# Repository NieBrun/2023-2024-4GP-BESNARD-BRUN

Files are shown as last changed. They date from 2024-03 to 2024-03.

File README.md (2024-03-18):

# 2023-2024 : Capteur low-tech Graphite (Niels Brun &amp; Paul Besnard)

## SOMMAIRE
*** 
  - [Contexte](#contexte)
  - [Livrables](#livrables)
  - [Matériel nécessaire](#matériel-nécessaire)
  - [1. Simulation électronique du capteur sous LTSpice](#simulation-électronique-du-capteur-sous-ltspice)
  - [2. Design du PCB sous KiCad](#design-du-pcb-sous-kicad)
  - [3. Code arduino](#code-arduino)
  - [4. Application android APK sous MIT App Inventor](#application-android-apk-sous-mit-app-inventor)
  - [5. Réalisation du shield](#réalisation-du-shield)
  - [6. Banc de test](#banc-de-test)
  - [7. Datasheet](#datasheet)
  - [Contact](#contact) 

*** 

## Contexte
&nbsp;&nbsp;&nbsp;&nbsp;&nbsp;&nbsp;Dans le cadre de l'UF "Du capteur au banc de test" se déroulant en 4ème année de Génie Physique de l’INSA Toulouse, nous avons développé un dispositif permettant de mesurer la contrainte. Le capteur du dispositif est basé sur l'article "Pencil Drawn Strain Gauges and Chemiresistors on Paper" (Cheng-Wei Lin*, Zhibo Zhao*, Jaemyung Kim & Jiaxing Huang). Il est simplement composé d'un bout de papier avec du crayon à papier. En déformant le papier, le nombre de particules de graphite composant le crayon à papier déposé sur le papier, reliées varie en fonction du type de déformation. Ce système granulaire subit une modification de résistance et de conductance. Grâce à cela, on  pourra remonter à la déformation tel une jauge de contrainte traditionnel. \
&nbsp;&nbsp;&nbsp;&nbsp;&nbsp;&nbsp;L'objectif est donc de pouvoir réaliser un dispositif permettant la mesure de déformation à partir d'un capteur low-tech. En passant par différentes étapes : simulations électroniques, design du PCB, code arduino et réalisation de datasheet.

## Livrables
- Un Shield PCB relié à une carte arduino UNO avec différents composants : un capteur graphite, un amplificateur transimpédance et un module bluetooth. Il peut également avoir un écran OLED, un flex sensor commercial, un potentiomètre digital, encodeur rotatoire ou des boutons.
- Un code arduino qui gère les différents composants cités précédemments (mesures de contraintes, échanges bluetooth et OLED, potentiomètre digital et boutons)
- Une application Android (sous MIT App Inventor) interfaçant le PCB et le code arduino.
- Un code arduino réalisant les essais de banc de test sur les mesures de contraintes.
- Une datasheet sur le capteur de contrainte.

Nous avons opté pour l'ajout d'un écran OLED, du flex sensor commercial, du potentiomètre digital. Egalement, nous avons choisi l'implémentation de 3 boutons plutôt que de l'encodeur rotatoire.

## Matériel nécessaire
Pour réaliser notre dispositif électronique, voici la liste des composants nécessaires :

- Résistances : 2 de 1 kOhms, 5 de 10 kOhms, 2 de 100 kOhms
- Capacités : 2 de 100 nF, 1 de 1 uF
- Arduino Uno
- Amplificateur opérationnel LTC1050
- Potentiomètre digital MCP41500
- Module Bluetooth HC05
- Ecran OLED 128x64
- Flex Sensor
- 3 boutons

## Simulation électronique du capteur sous LTSpice

## Design du PCB sous KiCad

## Code arduino

## Application android APK sous MIT App Inventor

## Réalisation du shield

## Banc de test

## Datasheet

## Contact

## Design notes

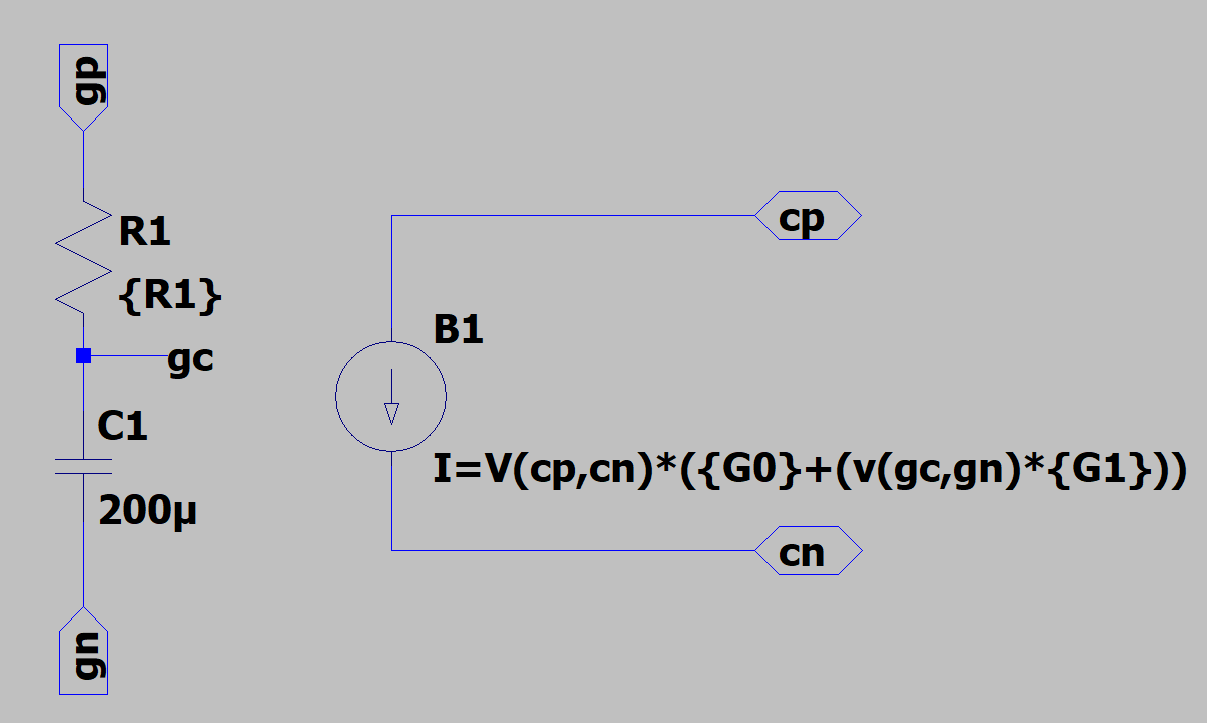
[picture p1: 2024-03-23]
Images/LTspice/capteur.png

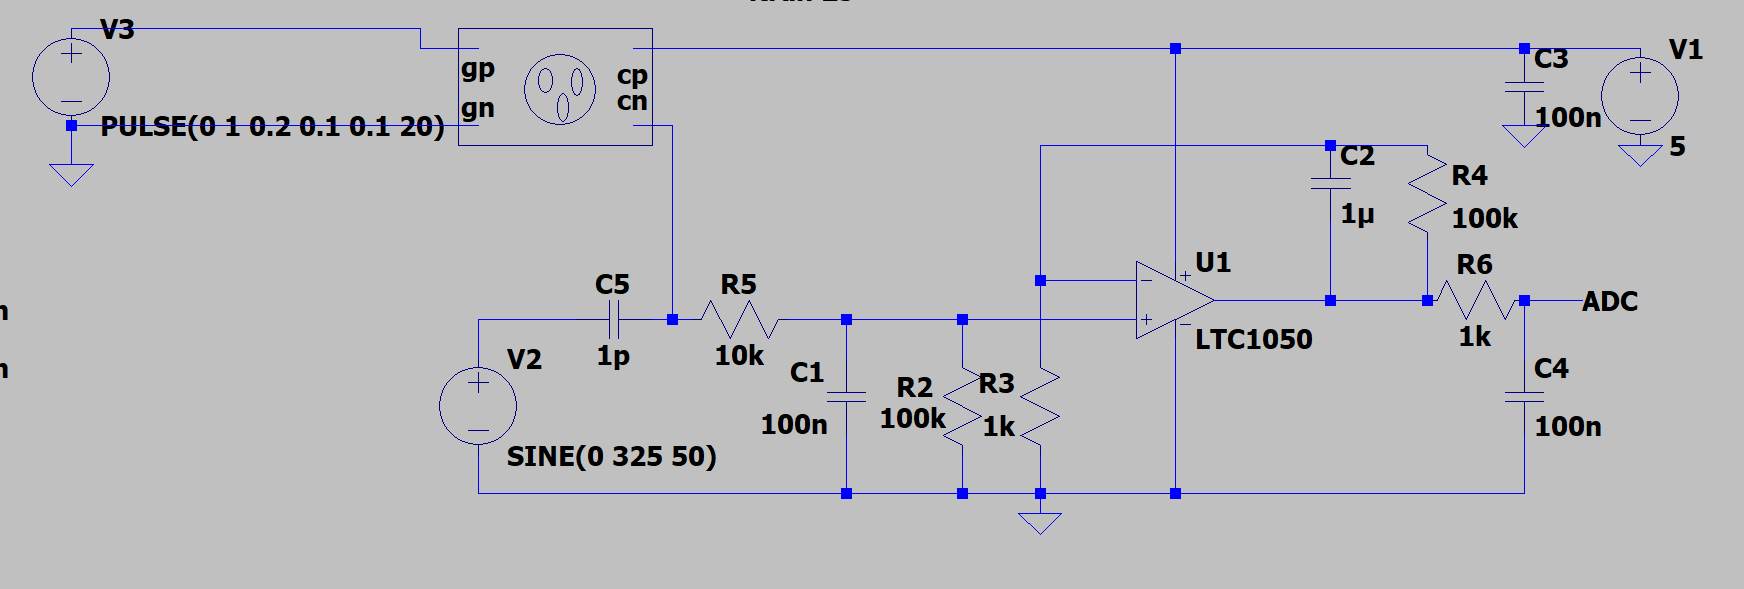
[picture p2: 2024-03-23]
Images/LTspice/schéma_global_ampli.png

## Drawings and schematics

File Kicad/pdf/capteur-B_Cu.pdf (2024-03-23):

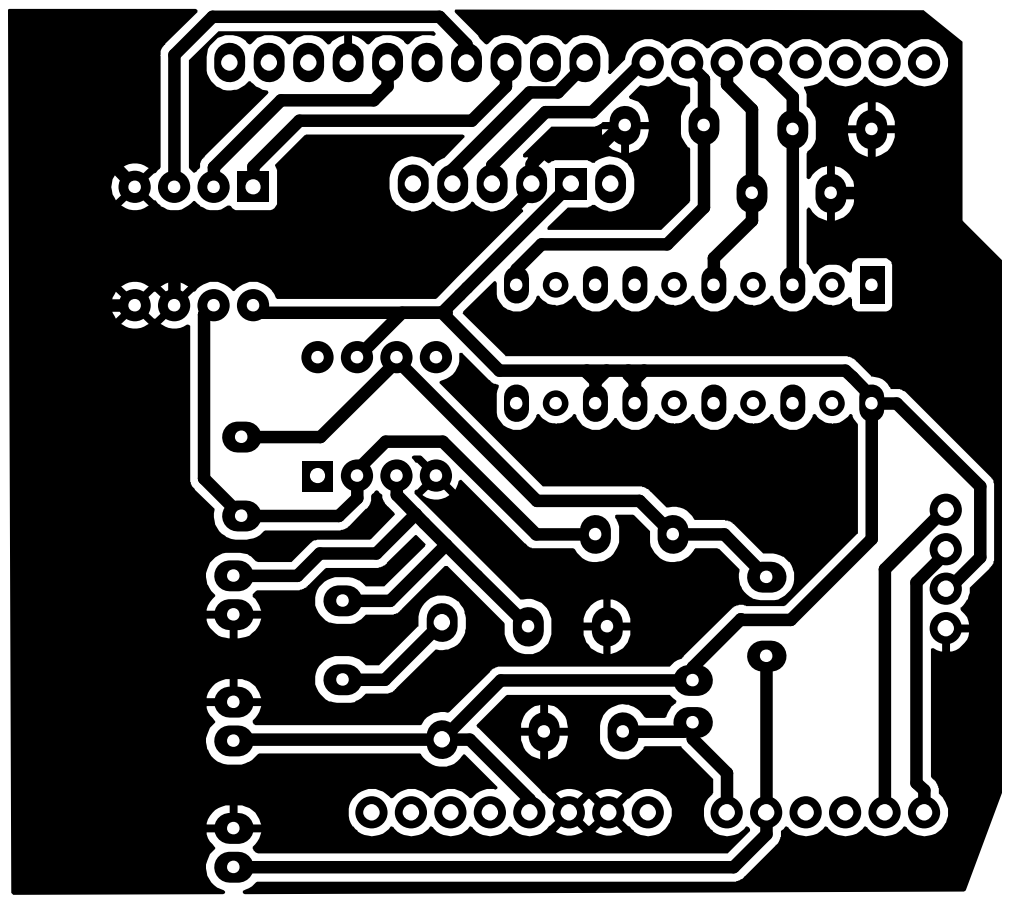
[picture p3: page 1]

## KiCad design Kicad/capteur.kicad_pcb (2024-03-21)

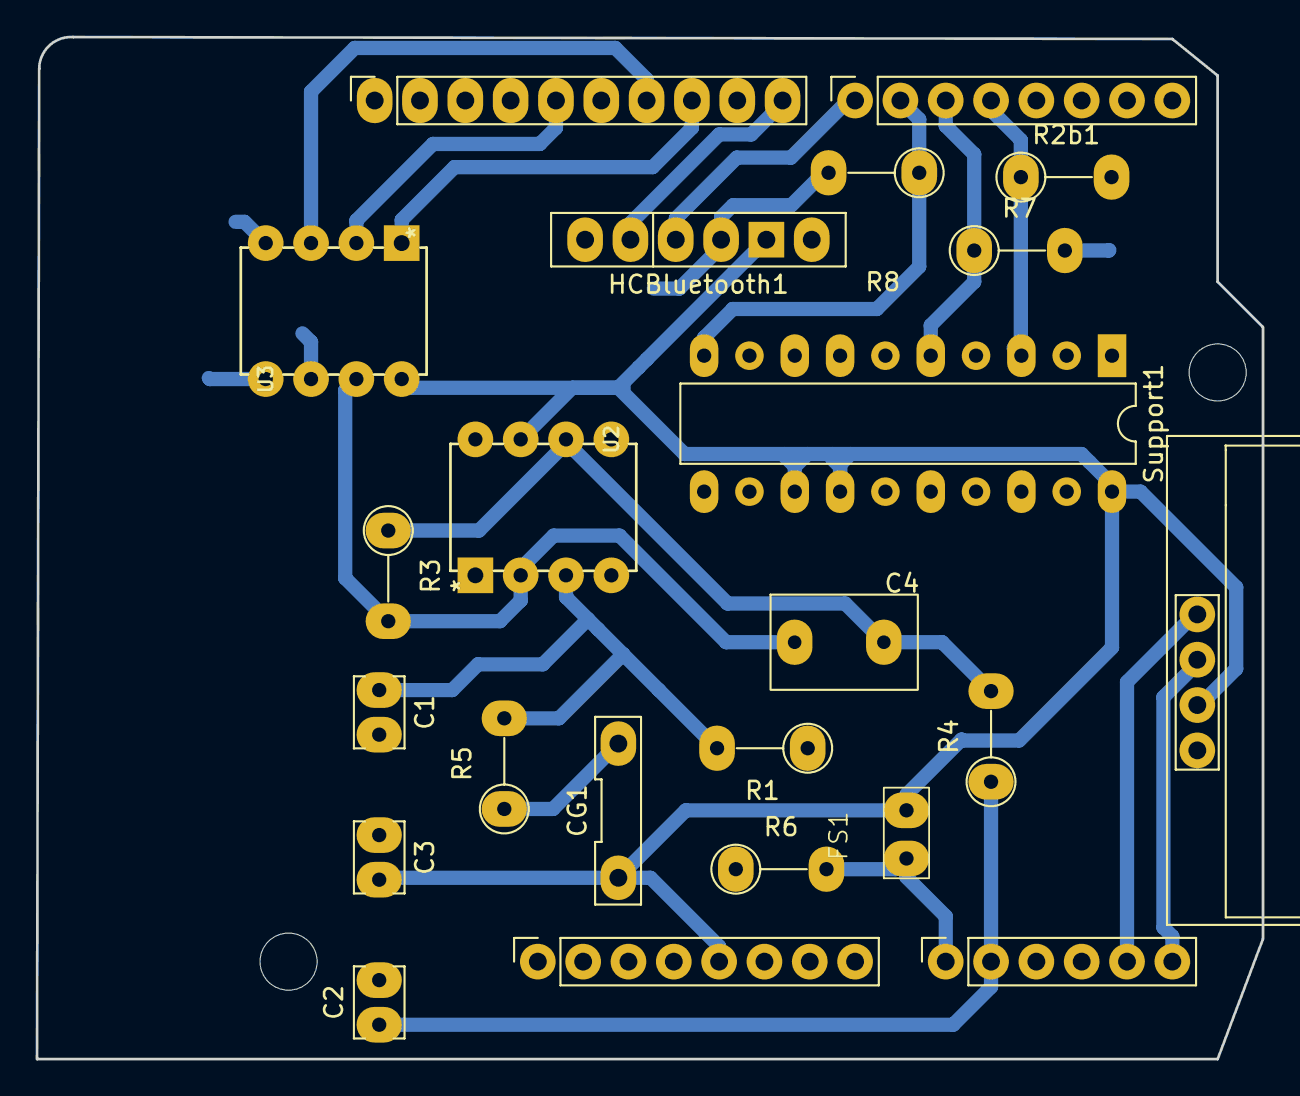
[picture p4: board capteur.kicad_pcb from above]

Board: 2 copper layers, 68.7 x 57.3 mm, 25 parts (0 on the bottom side), 18 nets.

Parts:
Brd1: SSD1306; 128x64OLED
C1, C2, C3: C; capa
C4: C; C4
CG1: CG
FS1: FlexSensor
HCBluetooth1: Bluetooth_HC-05
J1: Power; PinSocket_1x08_P2.54mm_Vertical
J2: Digital/PWM; PinSocket_1x10_P2.54mm_Vertical
J3: Analog; PinSocket_1x06_P2.54mm_Vertical
J4: Digital/PWM; PinSocket_1x08_P2.54mm_Vertical
MH2, MH3: MountingHole_3.2mm
R1, R2b1, R3, R4, R5, R6, R7, R8: R; R_Axial_DIN0207_L6.3mm_D2.5mm_P5.08mm_Vertical
Support1: DIP-20_W7.62mm_LongPads
U2: LTC1050ACN8; LTC
U3: MCP41100; LTC

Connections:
+5V: Brd1.2 (VCC), C3.2, CG1.1 (Vcc), FS1.2 (Vcc), HCBluetooth1.4 (Vcc), J1.5, Support1.1 (Vcc), Support1.4 (Vcc), Support1.5 (Vcc), U2.7 (V+), U3.8 (VDD)
/4: J4.4, R2b1.1, Support1.2 (Out)
/7: HCBluetooth1.2 (TX), J4.1
/8: HCBluetooth1.1 (RX), J2.10
/13: J2.5, U3.2 (SCK)
/*5: J4.3, R7.1, Support1.3 (Out)
/*6: J4.2, R8.1, Support1.6 (Out)
/*10: J2.8, U3.1 (~CS)
/*11: J2.7, U3.3 (SI)
/A0: FS1.1 (Vout), J3.1, R6.2
/A1: C2.1, J3.2, R4.1
/R2: C4.1, R3.2, U2.2 (-IN), U3.7 (PB0)
/SCL/A5: Brd1.3 (SCL), J2.1, J3.6
/SDA/A4: Brd1.4 (SDA), J2.2, J3.5
GND: Brd1.1 (GND), C1.2, C2.2, C3.1, HCBluetooth1.3 (GND), J1.6, J1.7, J2.4, R1.1, R2b1.2, R6.1, R7.2, R8.2, U2.4 (V-), U3.4 (VSS), U3.5 (PA0), U3.6 (PW0)
unnamed: CG1.2 (Vout), R5.1
unnamed: C1.1, R1.2, R5.2, U2.3 (+IN)
unnamed: C4.2, R3.1, R4.2, U2.6 (OUT)

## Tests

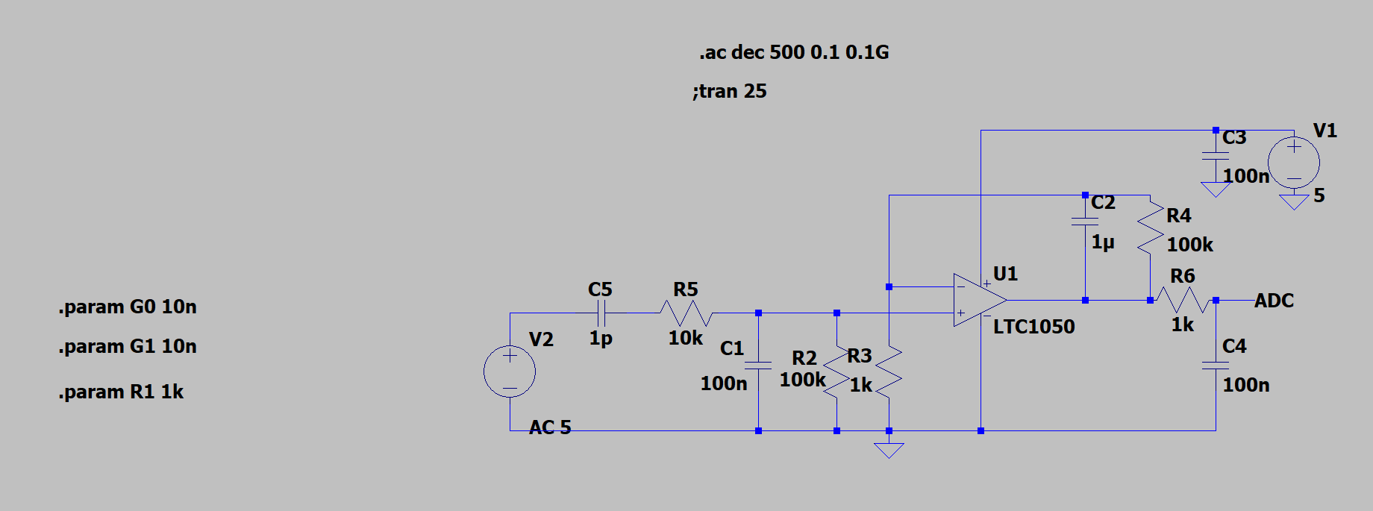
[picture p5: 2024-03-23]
Images/LTspice/test_circuits_filtres.png

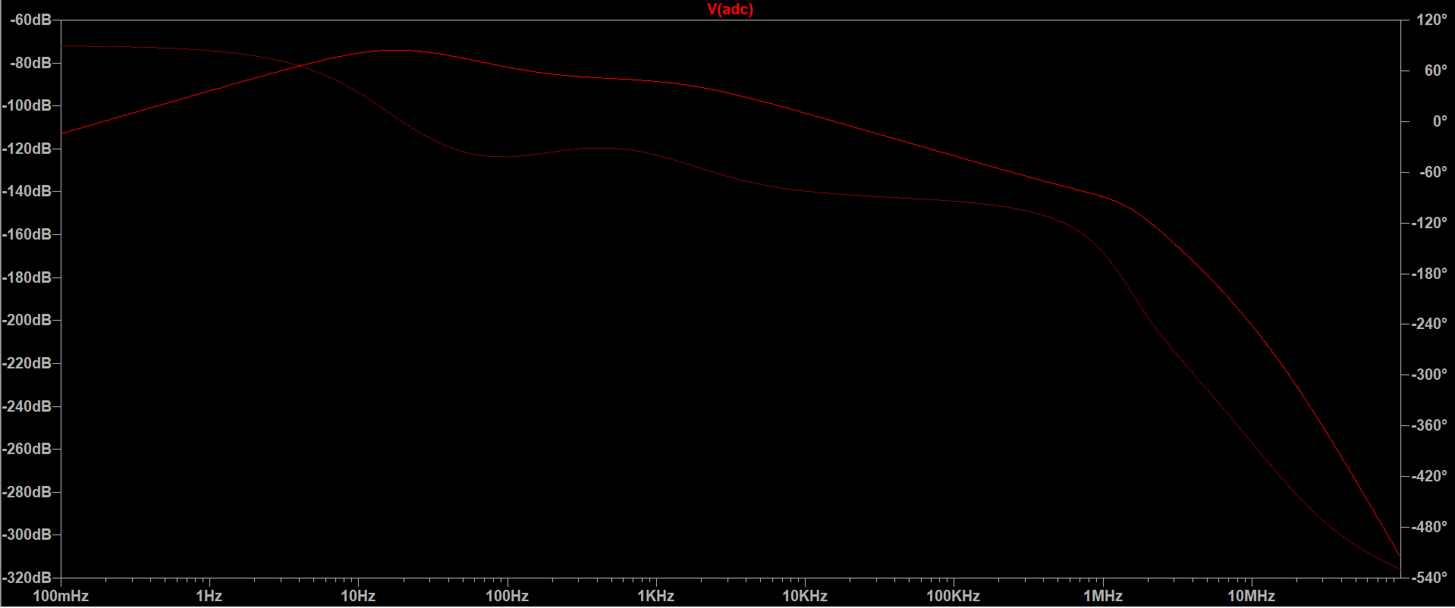
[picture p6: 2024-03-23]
Images/LTspice/tests_circuits_filtres_reponse.png

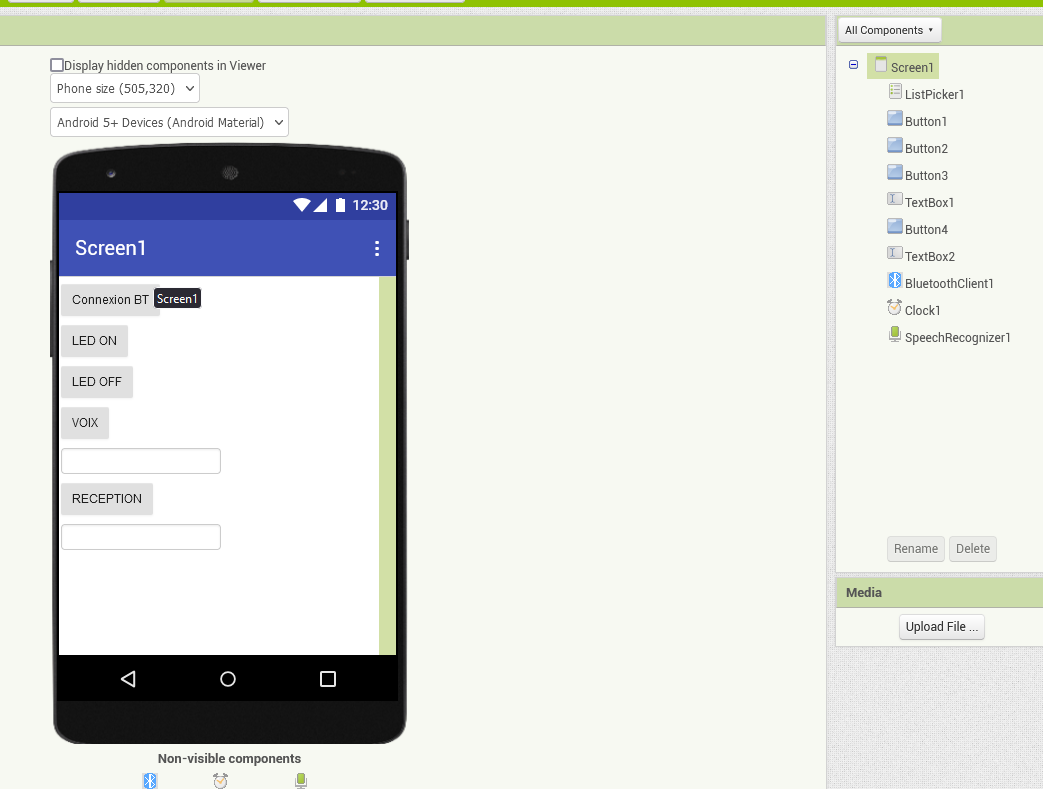
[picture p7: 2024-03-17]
Arduino/Test_Android/Face avant.png

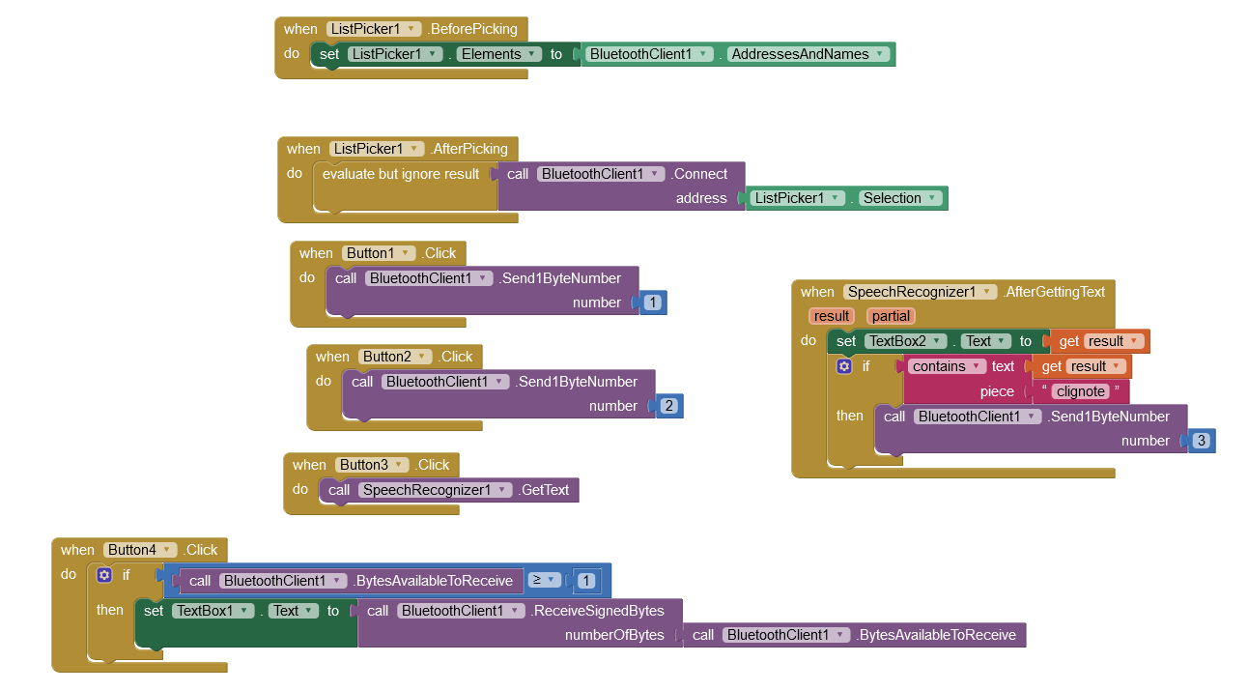
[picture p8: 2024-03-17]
Arduino/Test_Android/Face arrière.png

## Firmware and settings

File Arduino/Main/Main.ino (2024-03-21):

//Bluetooth
#include <SoftwareSerial.h>
#define rxPin 7 // Correspondant à la broche tx du module bluetooth
#define txPin 8 // Correspondant à la broche Rx du module bluetooth
#define baudrate 9600 
SoftwareSerial mySerial(rxPin ,txPin); //Definition du software serial

//OLED ATTENTION, la librarie utilisée (d'origine) consomme énormement de mémoire RAM en buffer qui n'est pas affiché sur arduino (possible même si affiché seulement 40%)
// Si le programme ne lance rien, même pas le setup, le problème peut venir de là.
// On peut soit baisser le nombre de pixels dans l'écran, soit utiliser d'autre librairie moins gourmande facilement trouvable sur internet.
#include <Adafruit_SSD1306.h>
#define nombreDePixelsEnLargeur 128        // Taille de l'écran OLED, en pixel, au niveau de sa largeur
#define nombreDePixelsEnHauteur 64        // Taille de l'écran OLED, en pixel, au niveau de sa hauteur
#define brocheResetOLED         -1          // Reset de l'OLED partagé avec l'Arduino (d'où la valeur à -1, et non un numéro de pin)
#define adresseI2CecranOLED     0x3C        // Adresse de "mon" écran OLED sur le bus i2c (généralement égal à 0x3C ou 0x3D)
Adafruit_SSD1306 ecranOLED(nombreDePixelsEnLargeur, nombreDePixelsEnHauteur, &Wire, brocheResetOLED);  

// MESURE Pin pour mesure de la tension du capteur //////////
const int capteurgraphitePin = 1;  // Pin A1
float calibre = pow(10,-6); // pour avoir des Mohms
// Variables pour éviter le delay 
unsigned long previousMillis = 0;        // will store last time LED was updated
// Variable pour cadencer l'acquisition
const long interval = 500;           // interval at which to blink (milliseconds) for MesureINST

// MESURE FLEX SENSOR
const int flexPin = A0;      // Pin connected to voltage divider output
const float VCC = 5;      // voltage at Ardunio 5V line
const float R_DIV = 10000.0;  // resistor used to create a voltage divider
const float flatResistance = 30000.0; // resistance when flat
const float bendResistance = 1000.0;  // resistance at 90 deg

//BOUTONS
const int buttonPin[] = {6,5,4};  // Pin connected to button
// Variables will change:
bool buttonState[3]= {LOW,LOW,LOW};            // the current reading from the input pin
bool lastButtonState[3] = {LOW,LOW,LOW};  // the previous reading from the input pin
bool reading; // variable pour stocker la lecture de l'etat des boutons
//Variable debouncing
unsigned long lastDebounceTime = 0;  // the last time the output pin was toggled
unsigned long debounceDelay = 50;    // the debounce time; increase if the output flickers

// MENU ///////////////////////////
int Position = 1; // Position par défaut dans le menu
int OK = 0;        // Si le bouton central a été appuyé ou pas
String text1="1 : Graphite INST"; // Les différents menus
String text2="2 : Graphite MOY";
String text3="3 : Flex Sensor";
String text4="4 : Calibration";

//Android
bool OK_TEL=0; // Si un bouton sur téléphone a été cliqué.

// Digital Potentiometer
#include <SPI.h>
const byte csPin           = 10;      // MCP42100 chip select pin
const int  maxPositions    = 256;     // wiper can move from 0 to 255 = 256 Positions
const long rAB             = 47000;   // 50k pot resistance between terminals A and B, mais pour ajuster au multimètre, je mets 47500
const byte rWiper          = 125;     // 125 ohms pot wiper resistance
const byte pot0            = 0x11;    // pot0 addr // B 0001 0001
const byte pot0Shutdown    = 0x21;    // pot0 shutdown // B 0010 0001
long R2;                              // Valeur de R2 calculé en sortir du potentiomètre
int PotPos;                           // Valeur de la position du potentiomètre entre 0 et 255

// Permet de gérer le potentiomètre
void setPotWiper(int addr, int pos) {
  pos = constrain(pos, 0, 255);            // limit wiper setting to range of 0 to 255
  digitalWrite(csPin, LOW);                // select chip
  SPI.transfer(addr);                      // configure target pot with wiper Position
  SPI.transfer(pos);
  digitalWrite(csPin, HIGH);               // de-select chip

  R2 = ((rAB * pos) / maxPositions ) + rWiper; // Calcul de R2 (résistance entre wiper et B)
  Serial.print(F(" Resistance wiper to B terminal: "));
  Serial.print(R2);
}


void setup() {
    // Initialisation de l'écran OLED
  if(!ecranOLED.begin(SSD1306_SWITCHCAPVCC, adresseI2CecranOLED))
    while(1);   
  mySerial.begin(baudrate); // Initialiser le port bluetooth
  Serial.begin(baudrate); // Initialiser le port série


  pinMode(buttonPin[0], INPUT);     // Initialise les boutons
  pinMode(buttonPin[1], INPUT);
  pinMode(buttonPin[2], INPUT);
  digitalWrite(csPin, HIGH);        // chip select default to de-selected
  SPI.begin();
  PotPos=Calibration();             // Calibration du potentiomètre en fonction du capteur
  }
  
void loop() {
  ChoixMenu(); // Affiche le menu et ses choix en boucle
}

// Permet de se balader dans les 4 menus différents
//MENU 1 : MesureINST : Mesure du capteur graphite toutes les 700ms~~
//MENU 2 : MesureMoyenne : Mesure du capteur graphite en faisant 50 mesures sur 2500ms
//MENU 3 : MesureINST : Mesure du capteur flex sensor
//MENU 4 : Calibration : Calibration du potentiomètre en fonction du capteur
void ChoixMenu(){
  // // MENU
  unsigned long currentMillis = millis ();
  if (currentMillis - previousMillis >= 500) 
  {
    previousMillis = currentMillis;
    ecranOLED.clearDisplay();                                   // Effaçage de l'intégralité du buffer
    ecranOLED.setTextSize(1);                           // Taille du texte
    ecranOLED.setCursor(0, 0);                          // Placement du texte
    ecranOLED.setTextColor(SSD1306_WHITE, SSD1306_BLACK);   // Couleur du texte, et couleur du fond
    CheckBoutons();   // Fonction primordiale : vérifie si les boutons physiques ne sont pas appuyé et ajuste la variable position, OK et OK_TEL (si un bouton sur tél n'est pas cliqué)
    if(Position==1)                       // Si nous sommes en position 1, affiche le texte correspondant (effet de surbrillance)
    {
      ecranOLED.setTextColor(SSD1306_BLACK, SSD1306_WHITE);
      ecranOLED.println(text1);
      ecranOLED.setTextColor(SSD1306_WHITE, SSD1306_BLACK);
      ecranOLED.println(text2);
      ecranOLED.println(text3);
      ecranOLED.println(text4);
      ecranOLED.display();                            // Transfert le buffer à l'écran
      if(OK_TEL==1) // Si un bouton sur téléphone est cliqué
      {
        OK_TEL=0; // Remet à 0
        MesureINST(); 
      }
      else if(OK==1) // Si le bouton central est cliqué
      {
        OK=0;     // Remet à 0
        MesureINST();
      }
    }
    else if (Position==2)// Si nous sommes en position 2, affiche le texte correspondant (effet de surbrillance)
    {
      ecranOLED.println(text1);
      ecranOLED.setTextColor(SSD1306_BLACK, SSD1306_WHITE);   // Couleur du texte, et couleur du fond
      ecranOLED.println(text2);
      ecranOLED.setTextColor(SSD1306_WHITE, SSD1306_BLACK);   // Couleur du texte, et couleur du fond
      ecranOLED.println(text3);
      ecranOLED.println(text4);
      ecranOLED.display();                            // Transfert le buffer à l'écran
       if(OK_TEL==1)
      {
        OK_TEL=0;
        MesureMoyenne();
      }
      else if(OK==1)
      {
        OK=0;
        MesureMoyenne();
      }
    }
    else if (Position==3)// Si nous sommes en position 3, affiche le texte correspondant (effet de surbrillance)
    {
      ecranOLED.println(text1);
      ecranOLED.println(text2);
      ecranOLED.setTextColor(SSD1306_BLACK, SSD1306_WHITE);
      ecranOLED.println(text3);
      ecranOLED.setTextColor(SSD1306_WHITE, SSD1306_BLACK); 
      ecranOLED.println(text4);
      ecranOLED.display();                            // Transfert le buffer à l'écran
       if(OK_TEL==1)
      {
        OK_TEL=0;
        FlexSensor();
      }
      else if(OK==1)
      {
        OK=0;
        FlexSensor();
      }
    }
    else if (Position==4)// Si nous sommes en position 4, affiche le texte correspondant (effet de surbrillance)
    {
      ecranOLED.println(text1);
      ecranOLED.println(text2);
      ecranOLED.println(text3);
      ecranOLED.setTextColor(SSD1306_BLACK, SSD1306_WHITE); 
      ecranOLED.println(text4);
      ecranOLED.display();
      if(OK_TEL==1)
      {
        OK_TEL=0;
        Calibration();
      }
      if(OK==1)
      {
        OK=0;
        Calibration();
      }    
    }
  }
}


// Vérifie si un bouton a été appuyé
void CheckBoutons()
{
  for (int i = 0; i < 3; i++) {
    reading = digitalRead(buttonPin[i]);

    // check to see if you just pressed the button
    // (i.e. the input went from LOW to HIGH), and you've waited long enough
    // since the last press to ignore any noise:
    // If the switch changed, due to noise or pressing:
    if (reading != lastButtonState[i]) {
      // reset the debouncing timer
      lastDebounceTime = millis();
    }

    if ((millis() - lastDebounceTime) > debounceDelay) {
      // whatever the reading is at, it's been there for longer than the debounce
      // delay, so take it as the actual current state:
      buttonState[i] = reading;
    }
    // save the reading. Next time through the loop, it'll be the lastButtonState:
    lastButtonState[i] = reading;
  }
  if(buttonState[0]==HIGH && Position < 4){ // Permet de descendre dans les menus sauf si en position 4
    Position++;
    buttonState[0]=LOW;}
  else if(buttonState[0]==HIGH && Position == 4){ // Si en position 4 et que l'utilisateur veut descendre, cela le fait remonter en position 1
    Position=1;
    buttonState[0]=LOW;
  }
  if(buttonState[1]==HIGH){ // si bouton central appuyé, alors cela correspond à une validation
    OK=1;
    buttonState[1]=LOW;
    }
  if(buttonState[2]==HIGH && Position > 1){ // Permet de monter dans les menus sauf si en position 1
    Position--;
    buttonState[2]=LOW;
    }
  else if(buttonState[2]==HIGH && Position == 1){// Si en position 1 et que l'utilisateur veut monter, cela le fait descendre en position 4
    Position=4;
    buttonState[2]=LOW;
  }
    if(mySerial.available()>0){ // Lis ce qui a été envoyé sur le module Bluetooth si nécessaire
    switch (mySerial.read()) {
    case 1: // si arduino reçois le chiffre 1 alors
      Position=1;
      //OK=1;
      OK_TEL=1;
      Serial.println(1);
      break;
    case 2: // si arduino reçois le chiffre 2 alors
      Position=2;
      //OK=1;
      OK_TEL=1;
      Serial.println(2);
      break;
    case 3: // si arduino reçois le chiffre 3 alors
      Position=3;
      //OK=1;
      OK_TEL=1;
      Serial.println(3);
      break;
    case 4: // si arduino reçois le chiffre 4 alors 
      Position=4;
      //OK=1;
      OK_TEL=1;
      Serial.println(4);
      break;
    }                   // wait for a second
  }
}


//Amelioration: faire une fonction de tout ce qui est affichage répété dans les 3 fonctions suivantes
// Permet de mesurer toutes les 500ms la valeur du capteur graphite
void MesureINST()
{
  float R3=100000;
  int Vcc=5;
  float R1=100000;
  int R5=10000;
  float Vadc=0;
  float Res=-1;
  // Affiche l'affichage de mesureINST avant les mesures réelles, comme cela, l'utilisateur peut arreter d'appuyer sur le bouton OK et cela évite de le faire sortir du programme
  ecranOLED.clearDisplay();                                   // Effaçage de l'intégralité du buffer
  ecranOLED.setTextSize(1);                   // Taille des caractères (1:1, puis 2:1, puis 3:1)
  ecranOLED.setCursor(0, 0);
  ecranOLED.setTextColor(SSD1306_WHITE, SSD1306_BLACK);   // Couleur du texte, et couleur du fond
  ecranOLED.println(F("Mesure instantannee : "));
  ecranOLED.display();    
  delay(1000);
  do
  {    
    // MESURE
    unsigned long currentMillis = millis();
    if (currentMillis - previousMillis >= interval) {
      previousMillis = currentMillis;
      Vadc = analogRead(capteurgraphitePin)*5.0/1024.0; // Valeur lu en voltage sortant du capteur
      Res=(R1*(1+R3/R2)*Vcc/Vadc-R1-R5)*calibre; // Calcul de la résistance
      DisplayAndTransmitter(Res,1); // Transmet la donnée à afficher à l'ordi, à l'écran et au bluetooth
      CheckBoutons();
      }
  }while(!(OK == 1 || OK_TEL == 1)); // Tant que le bouton OK n'est pas appuyé, continue
  //Position=1;
  OK=0;
  //OK_TEL=0;
  //Permet de donner l'impression à l'utilisateur qu'il est sorti de l'écran MesureINST
  ecranOLED.clearDisplay();                                   // Effaçage de l'intégralité du buffer
  ecranOLED.setCursor(0, 0);
  ecranOLED.setTextSize(1);                 
  ecranOLED.setTextColor(SSD1306_BLACK, SSD1306_WHITE);   // Couleur du texte, et couleur du fond
  ecranOLED.println(text1);
  ecranOLED.setTextColor(SSD1306_WHITE, SSD1306_BLACK);   // Couleur du texte, et couleur du fond
  ecranOLED.println(text2);
  ecranOLED.println(text3);
  ecranOLED.println(text4);
  ecranOLED.display();    
  delay(1000);
 
} 

//Mesure du capteur graphite sur 50 mesures en 2500ms, forme similaire à MesureINST
void MesureMoyenne(){
  float R3=100000;
  int Vcc=5;
  float R1=100000;
  int R5=10000;
  float Vadc=0;
  float Res=-1;
  ecranOLED.clearDisplay();                                   // Effaçage de l'intégralité du buffer
  ecranOLED.setTextSize(1);                   // Taille des caractères (1:1, puis 2:1, puis 3:1)
  ecranOLED.setCursor(0, 0);
  ecranOLED.setTextColor(SSD1306_WHITE, SSD1306_BLACK);   // Couleur du texte, et couleur du fond
  ecranOLED.println(F("Mesure moyennee :"));
  ecranOLED.display();    
  delay(1000);
  do
  { 
    float moyenne=0;  
    for (int i = 0; i < 50; i++) {
      moyenne=moyenne+(analogRead(capteurgraphitePin)*5/1024); 
      CheckBoutons();
      delay(50);
    }
    moyenne=moyenne/50; // Fais la moyenne sur les 50 mesures
    Res=(R1*(1+R3/R2)*Vcc/moyenne-R1-R5)*calibre; // Calcul de la résistance à partir de la valeur lue moyenne, possible de faire la moyenne des résistance calculées
    //Serial.print(F("Mesure moyennee :"));
    //Serial.println(Res);
    DisplayAndTransmitter(Res,2); // Transmet la donnée à afficher à l'ordi, à l'écran et au bluetooth
  }while(!(OK == 1 || OK_TEL == 1));
  //Position=2;
  OK=0;
  //OK_TEL=0;
  ecranOLED.clearDisplay();                                   // Effaçage de l'intégralité du buffer
  ecranOLED.setCursor(0, 0);
  ecranOLED.setTextSize(1);                 
  ecranOLED.println(text1);
  ecranOLED.setTextColor(SSD1306_BLACK, SSD1306_WHITE);   // Couleur du texte, et couleur du fond
  ecranOLED.println(text2);
  ecranOLED.setTextColor(SSD1306_WHITE, SSD1306_BLACK);   // Couleur du texte, et couleur du fond
  ecranOLED.println(text3);
  ecranOLED.println(text4);
  ecranOLED.display();    
  delay(1000);
}

// Mesure du flex sensor
void FlexSensor(){
  int ADCflex;
  float Vflex;
  float Rflex;
  ecranOLED.clearDisplay();                                   // Effaçage de l'intégralité du buffer
  ecranOLED.setTextSize(1);                   // Taille des caractères (1:1, puis 2:1, puis 3:1)
  ecranOLED.setCursor(0, 0);
  ecranOLED.setTextColor(SSD1306_WHITE, SSD1306_BLACK);   // Couleur du texte, et couleur du fond
  ecranOLED.println(F("Mesure Flex Sensor:"));
  ecranOLED.display();    
  delay(1000);
  do
  {  
    // Read the ADC, and calculate voltage and resistance from it
    ADCflex = analogRead(flexPin);
    Vflex = ADCflex * VCC / 1023.0;
    Rflex = R_DIV * (VCC / Vflex - 1.0); // Calcul de la résistance du flex
    // Use the calculated resistance to estimate the sensor's bend angle:
    // float angle = map(Rflex, flatResistance, bendResistance, 0, 90.0);
    // Serial.println("Bend: " + String(angle) + " degrees");
    delay(500);
    DisplayAndTransmitter(Rflex,3);
    CheckBoutons();
  }while(!(OK == 1 || OK_TEL == 1));
  //Position=3;
  OK=0;
  //OK_TEL=0;    
  ecranOLED.clearDisplay();                                   // Effaçage de l'intégralité du buffer
  ecranOLED.setCursor(0, 0);
  ecranOLED.setTextSize(1);
  ecranOLED.setTextColor(SSD1306_WHITE, SSD1306_BLACK);   // Couleur du texte, et couleur du fond                 
  ecranOLED.println(text1);
  ecranOLED.println(text2);
  ecranOLED.setTextColor(SSD1306_BLACK, SSD1306_WHITE);
  ecranOLED.println(text3);
  ecranOLED.setTextColor(SSD1306_WHITE, SSD1306_BLACK); 
  ecranOLED.println(text4);
  ecranOLED.display();
  delay(1000);
}
// Transmet la donnée à afficher à l'ordi, à l'écran et au bluetooth
void DisplayAndTransmitter(float VALUE, int choix){
  char ResASCII[10];
  dtostrf(VALUE, 5, 2, ResASCII); //Transforme le float en chaine de caractères
  ecranOLED.clearDisplay();                                   // Effaçage de l'intégralité du buffer
  ecranOLED.setTextSize(1);                   // Taille des caractères (1:1, puis 2:1, puis 3:1)
  ecranOLED.setCursor(0, 0);
  ecranOLED.setTextColor(SSD1306_WHITE, SSD1306_BLACK);   // Couleur du texte, et couleur du fond
  if(choix==1){ecranOLED.println(F("Mesure instantannee :"));}
  else if(choix==2){ecranOLED.println(F("Mesure moyennee :"));}
  else if(choix==3){ecranOLED.println(F("Mesure Flex Sensor :"));}
  else if(choix==4){ecranOLED.println(F("Calibration en cours"));}
  ecranOLED.setTextSize(3);                   // Ecris en gros
  ecranOLED.setCursor(0, 30); // Ecris à gauche de l'écran
  ecranOLED.print(ResASCII); // Envoyer sur l'écran la valeur
  mySerial.write(ResASCII); // Envoyer sur le port bluetooth la valeur acquise
  Serial.println(ResASCII); // Afficher sur le port série la valeur de la tension mesuré en bytes
  ecranOLED.display();                            // Transfert le buffer à l'écran
  delay(50);

}

//Calibration basé sur un principe de dichotimie, voir internet. Essaie de se placer au centre de la plage des 1024 valeurs
int Calibration(){
  ecranOLED.clearDisplay();                                   // Effaçage de l'intégralité du buffer
  ecranOLED.setTextSize(1);                   // Taille des caractères (1:1, puis 2:1, puis 3:1)
  ecranOLED.setCursor(0, 0);
  ecranOLED.setTextColor(SSD1306_WHITE, SSD1306_BLACK);   // Couleur du texte, et couleur du fond
  ecranOLED.println(F("Calibration en cours"));
  ecranOLED.display();    
  delay(2000);   
  int Vadc=analogRead(capteurgraphitePin);
  int tolerance=20; //Tolerance : 512+-20
  int V_Cible = 512;
  int a = 0;
  int b = 255;
  int ite=0;
  while(abs(Vadc - V_Cible) > tolerance)
  {
    Vadc=0;
    ite++;
    PotPos = (a + b)/2; // Prend le milieu  des 2 valeurs précédentes
    setPotWiper(pot0,int(PotPos));
    for(int i=0;i<3;i++)
    {
      Vadc += analogRead(capteurgraphitePin);
      delay(100);
    }
    Vadc = int(Vadc/3);
    Serial.print(F("Position Pota :"));
    Serial.print(PotPos);
    Serial.print(F(". Valeur lue :"));
    Serial.println(Vadc); // Afficher sur le port série la valeur de la tension mesuré en bytes
    DisplayAndTransmitter(PotPos,4);
    if(Vadc > V_Cible){ // on change le minimum ou le maximum
      a = PotPos;}
    else{
      b = PotPos;}
    if(ite>12){break;}
  }
  Serial.print(F("Finie. Pota en "));
  Serial.println(PotPos); // Afficher sur le port série la valeur de la tension mesuré en bytes
  return PotPos;

}

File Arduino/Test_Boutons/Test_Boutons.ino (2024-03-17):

#define baudrate 9600 
#include <SoftwareSerial.h>


// constants won't change. They're used here to set pin numbers:
const int buttonPin[] = {6,5,4};  // the number of the pushbutton pin



const int ledPin = 13;    // the number of the LED pin

// Variables will change:
int ledState = HIGH;        // the current state of the output pin
int buttonState[3];            // the current reading from the input pin
int lastButtonState[3] = {LOW,LOW,LOW};  // the previous reading from the input pin
int reading[3];

// the following variables are unsigned longs because the time, measured in
// milliseconds, will quickly become a bigger number than can be stored in an int.
unsigned long lastDebounceTime = 0;  // the last time the output pin was toggled
unsigned long debounceDelay = 50;    // the debounce time; increase if the output flickers

void setup() {
  pinMode(buttonPin[0], INPUT);
  pinMode(buttonPin[1], INPUT);
  pinMode(buttonPin[2], INPUT);
  pinMode(ledPin, OUTPUT);

  // set initial LED state
  digitalWrite(ledPin, ledState);

  Serial.begin(baudrate); // Initialiser le port série
}

void loop() {
  reading[0] = digitalRead(buttonPin[0]);
  digitalWrite(ledPin, reading[0]);
  Serial.println(reading[0]);
  // // read the state of the switch into a local variable:
  // for (int i = 0; i < 3; i++) {
  //   reading[i] = digitalRead(buttonPin[i]);
  

  // // check to see if you just pressed the button
  // // (i.e. the input went from LOW to HIGH), and you've waited long enough
  // // since the last press to ignore any noise:

  // // If the switch changed, due to noise or pressing:
  // if (reading[i] != lastButtonState[i]) {
  //   // reset the debouncing timer
  //   lastDebounceTime = millis();
  // }

  // if ((millis() - lastDebounceTime) > debounceDelay) {
  //   // whatever the reading is at, it's been there for longer than the debounce
  //   // delay, so take it as the actual current state:

  //   // if the button state has changed:
  //   if (reading[i] != buttonState[i]) {
  //     buttonState[i] = reading[i];

  //     // only toggle the LED if the new button state is HIGH
  //     if (buttonState[i] == HIGH) {
  //       ledState = !ledState;
  //     }
  //   }
  // }
  
  // // set the LED:
  // digitalWrite(ledPin, ledState);

  // // save the reading. Next time through the loop, it'll be the lastButtonState:
  // lastButtonState[i] = reading[i];
  // }
}

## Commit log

2024-03-17 Add of kicad
    [capteur.kicad_pcb, capteur.kicad_sch]
2024-03-17 Add of main file, manage all components and android apk
    Not the final version: android apk need fix and so arduino (probably). Optimisation of MesureINST, MesureMoyenne and FlexSensor possible (all OLED stuff). Care to RAM usage due to OLED screen which is apparently not count in arduino IDE
    [Main.ino]
2024-03-18 Small changes of kicad
    [capteur.kicad_pcb]
2024-03-19 Ajout du calcul de résistance du capteur, à compléter
2024-03-21 Add of comments and calculation of graphite sensor resistance
    [capteur.kicad_pcb, capteur.kicad_sch]
2024-03-23 minor change of kicad schematic
    [capteur.kicad_sch]

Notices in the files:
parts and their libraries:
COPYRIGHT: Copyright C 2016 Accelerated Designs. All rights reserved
